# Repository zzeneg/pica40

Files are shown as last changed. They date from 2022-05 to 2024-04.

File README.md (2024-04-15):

# Pica40 v2

Split keyboard with 40 keys using XIAO controllers.

_Pica pica - european (common) magpie_

## Features

- 40 keys
- high profile (regular MX switches with hotswap sockets) or low profile (soldered low-profile ChocV2 switches)
- wired/wireless versions
- aggressive stagger
- slightly splayed for pinky columns

### Wired version

- XIAO RP2040 controller
- QMK firmware
- USB-C or TRRS connection between splits
- one rotary encoder (without click)
- status LED

### Wireless version

- XIAO nRF52840 BLE controller
- ZMK firmware
- two rotary encoders (without click, only master side encoder is currently supported by ZMK)
- on/off toggle
- battery connectors

> [!NOTE]
> I created a beta version with small improvements for wireless version - https://github.com/zzeneg/pica40/tree/v2.2-beta?tab=readme-ov-file#v22. I'm fairly confident it should work but I'm not able to verify it at the moment. You can order it at your own risk, let me know if everything worked.

## Photos

wired version with 3d printed case

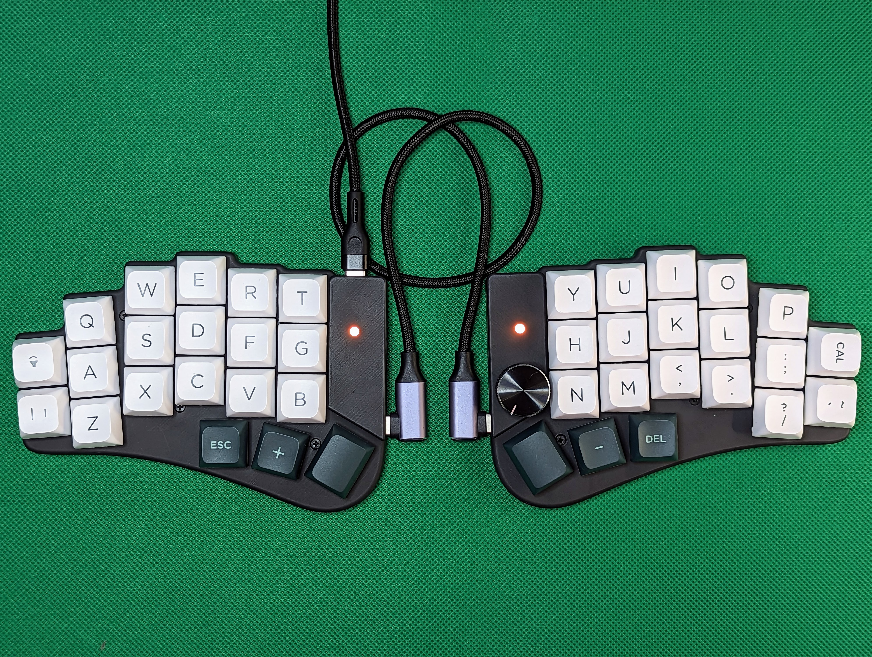
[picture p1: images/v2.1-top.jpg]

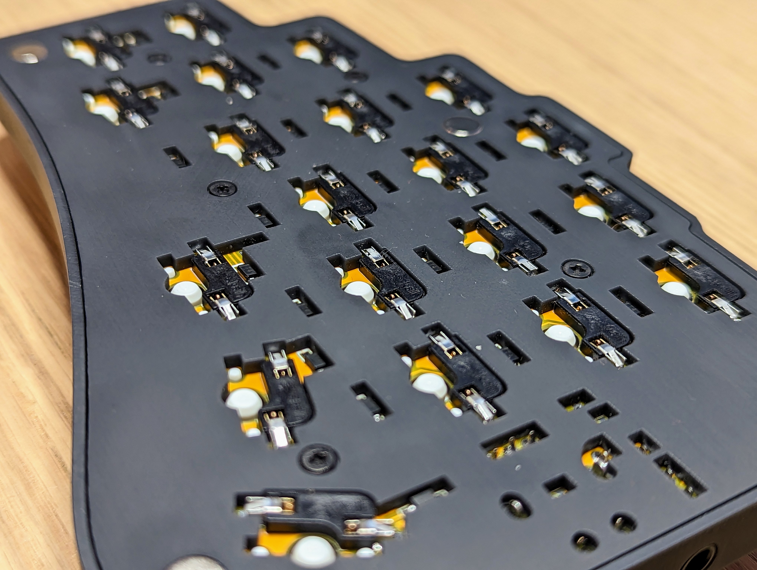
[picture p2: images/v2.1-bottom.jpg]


wired/wireless versions with Choc V2

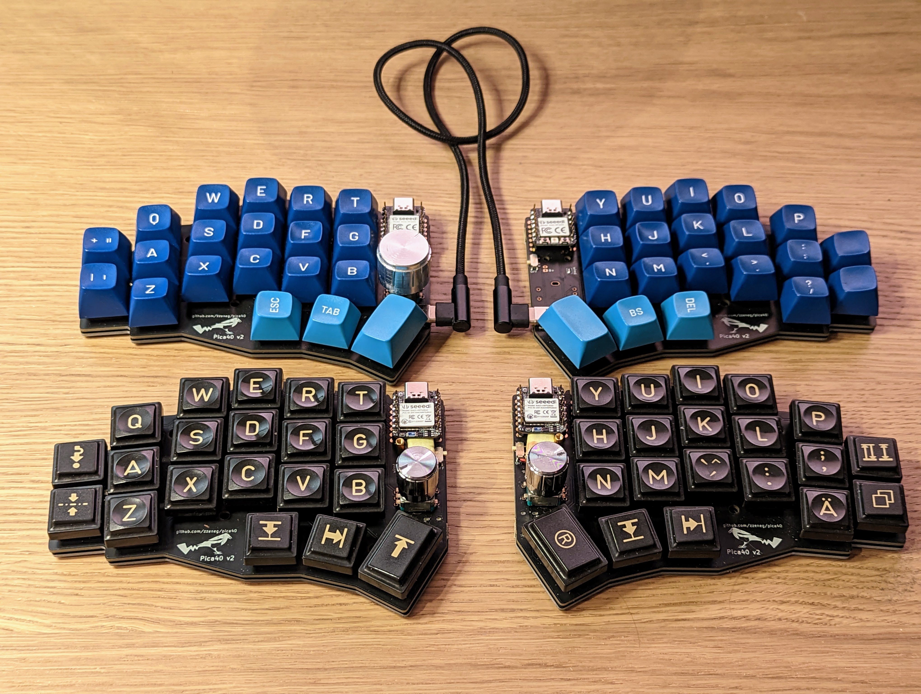
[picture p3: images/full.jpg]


Pica40 family - ChocV2 with low profile keycaps, ChocV2 with MT3 keycaps, Pica40 v1 with MT3 keycaps, regular switches and hotswap sockets

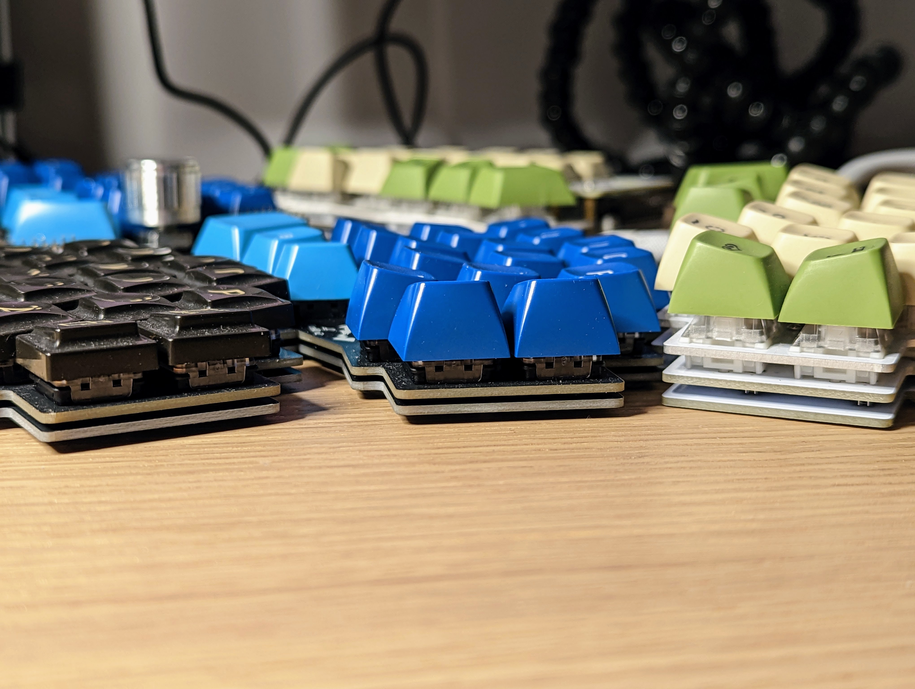
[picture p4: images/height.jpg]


## Firmware

- QMK - available in [main repository](https://github.com/qmk/qmk_firmware/tree/master/keyboards/pica40), also check [my fork](https://github.com/zzeneg/qmk_firmware/tree/feature/zzeneg/keyboards/pica40) for most recent updates. [Compiled file](firmware/qmk/pica40_rev2_zzeneg.uf2).
- Vial - [my fork](https://github.com/zzeneg/vial-qmk/tree/feature/zzeneg/keyboards/pica40). [Compiled file](firmware/vial/pica40_rev2_vial-zzeneg.uf2).
- ZMK - [Source code](https://github.com/zzeneg/zmk-config), [compiled left](firmware/zmk/pica40_left.uf2), [compiled right](firmware/zmk/pica40_right.uf2), [reset](firmware/zmk/settings_reset.uf2)

## Gerber files

- [PCB](./pcb/production/full.zip)
- [Bottom plate](./case/production/bottom.zip)

## Case files (STL - 3d printed, MX hotswap only)

All files are in [stl](./stl) folder.

### Top:

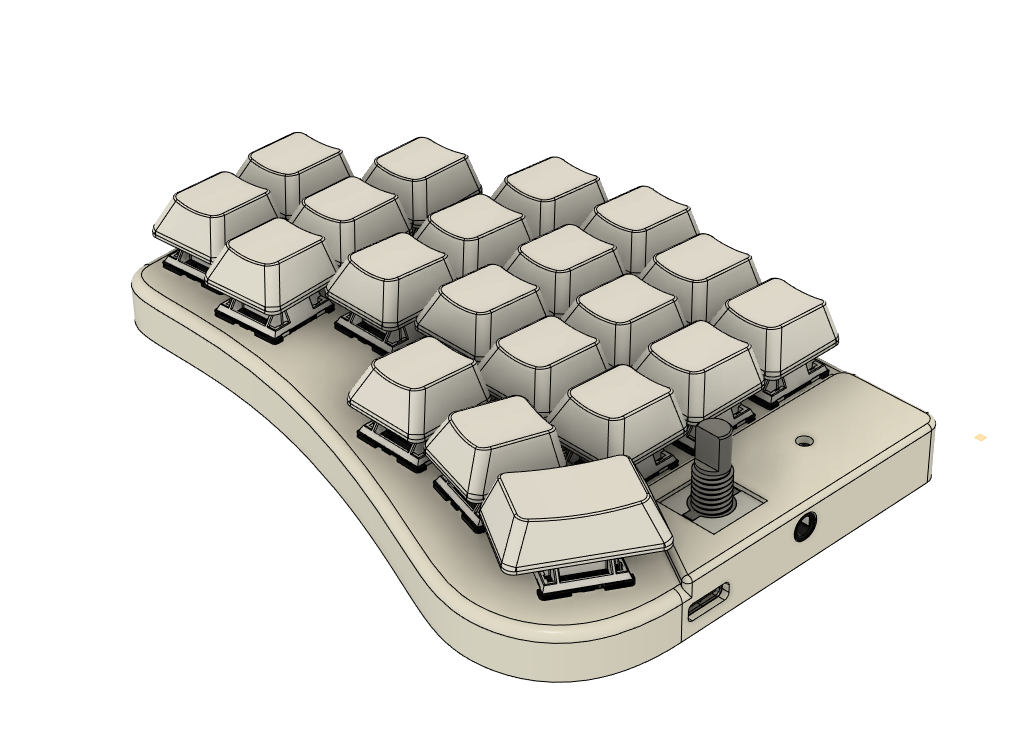
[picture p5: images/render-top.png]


- wired/wireless versions
- with and without encoders
- normal and thin versions (see bottom parts for difference)

### Bottom:

Normal version - solid cover, cutouts for legs.
Thin version - 1.2mm lower than normal version, cutouts for all elements. Has additional cutouts for magnets.

Thin vs normal:
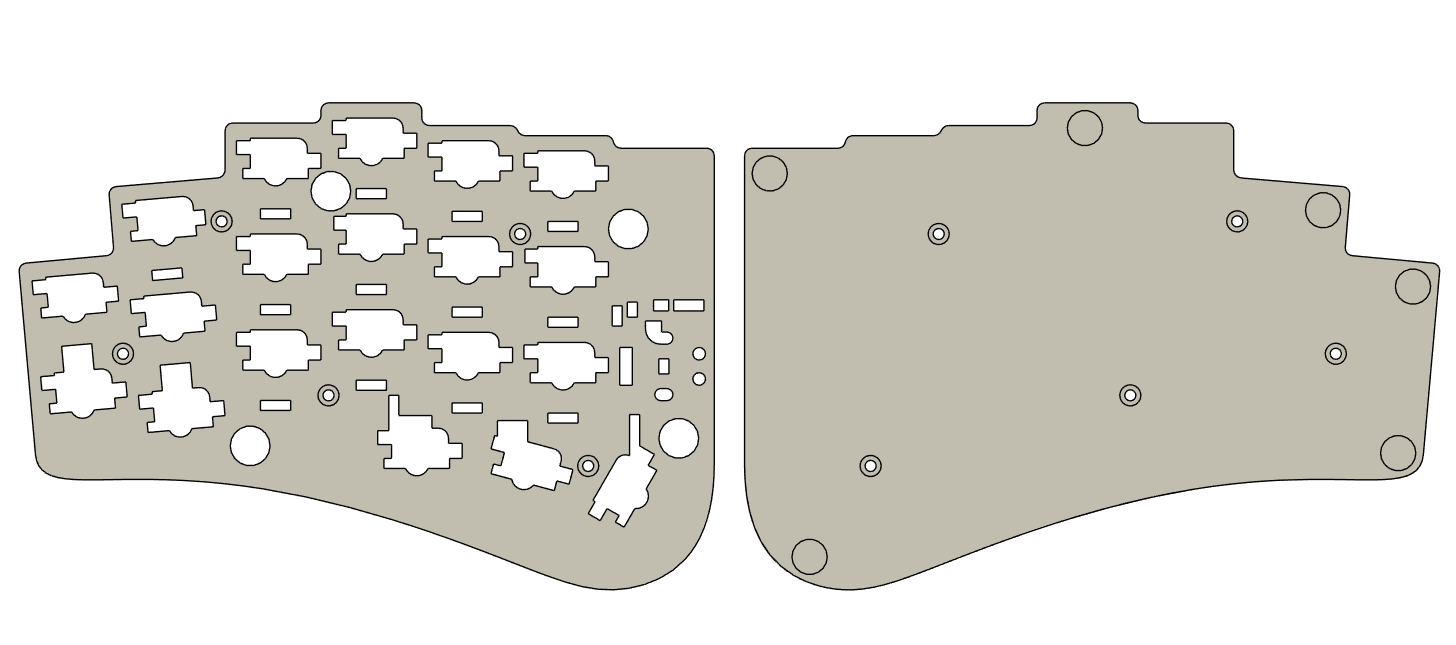
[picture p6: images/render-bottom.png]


## Case files (DXF - for metal/acrylic)

- [Curved bottom for MX hotswap with 3D printed case](dxf/bottom-curved.dxf)
- [Bottom for soldered ChocV2](dxf/bottom.dxf)
- [MCU cover](dxf/cover.dxf)
- [MCU cover with encoder hole](dxf/cover-hole.dxf)

## Bill of materials

- PCBs
- 2 XIAO MCUs - [RP2040](https://www.seeedstudio.com/XIAO-RP2040-v1-0-p-5026.html) for wired version, [nRF52840](https://www.seeedstudio.com/Seeed-XIAO-BLE-nRF52840-p-5201.html) for wireless
- 40 SMD SOD-123 1N4148 diodes
- 1 or 2 EC11/12 rotary encoder with knob (diameter up to 20mm)
- _[MX hotswap version]_ 3d printed case (top and bottom, left and right - 4 files)
- _[MX hotswap version]_ 40 hotswap sockets
- _[MX hotswap version]_ [M2 standoffs](https://www.aliexpress.com/item/4001271908929.html) (4mm for thin, 5mm for normal), 3mm [M2 screws with flat head](https://www.aliexpress.com/item/4001248931159.html)
- _[MX hotswap thin version]_ [8x2mm magnets](https://www.aliexpress.com/item/1005002285176336.html) (optional)
- _[ChocV2 soldered version]_ FR4/metal/acrylic bottom plates, metal/acrylic MCU cover (optional)
- _[ChocV2 soldered version]_ 6mm M2 screws, M2 nuts and washers
- _[Wired only]_ [USB-C 16pin connectors](https://www.aliexpress.com/item/1005003670899595.html)
- _[Wired only]_ [TRRS PJ-320A connectors](https://www.aliexpress.com/item/1005001928651798.html)
- _[Wireless only]_ [2x on/off toggle MSK-12C02](https://www.aliexpress.com/item/4000685483225.html)
- _[Wireless only]_ 2x Li-Ion 3.7V battery (up to 25x14x5 for standard case)
- [7mm legs](https://www.aliexpress.com/item/1005002995402961.html) or [rubber sheet](https://www.aliexpress.com/item/1005003938672544.html) (recommended for thin version)

## Build log

**TODO**

## Development

For proper KiCad setup install my [zzkeeb](https://github.com/zzeneg/zzkeeb/blob/main/README.md#installation) library.

## Changelog

### V2.1

- added TRRS support
- wired version supports rotary encoder on any side
- remove unused for FR4/acrylic/metal sandwich case, 3D printing is better and cheaper
- improved 3D printed case with a new shape and parts

### V2

- reworked to true split with two XIAO MCUs controllers
- added splay to pinky columns
- all case/pcb files are not compatible with V1

### V1

- split with single Pro Micro based MCU and handwired connection

## Support

If you like my work and want to support my future designs, please consider [sponsorship](https://github.com/sponsors/zzeneg).

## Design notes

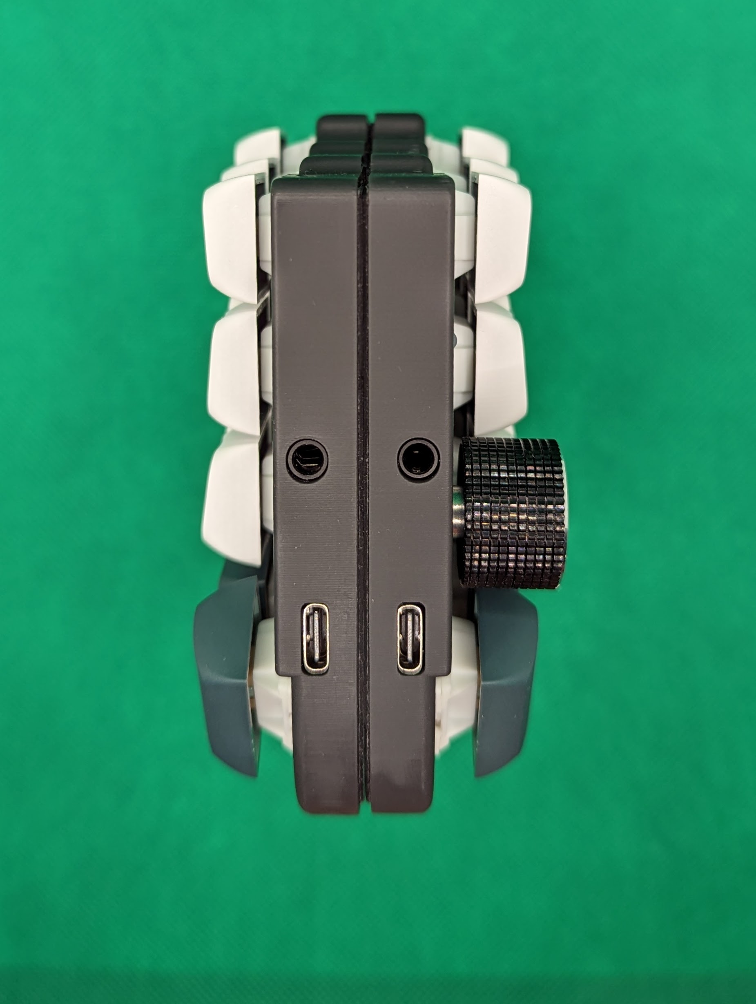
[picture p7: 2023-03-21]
images/v2.1-ports.jpg

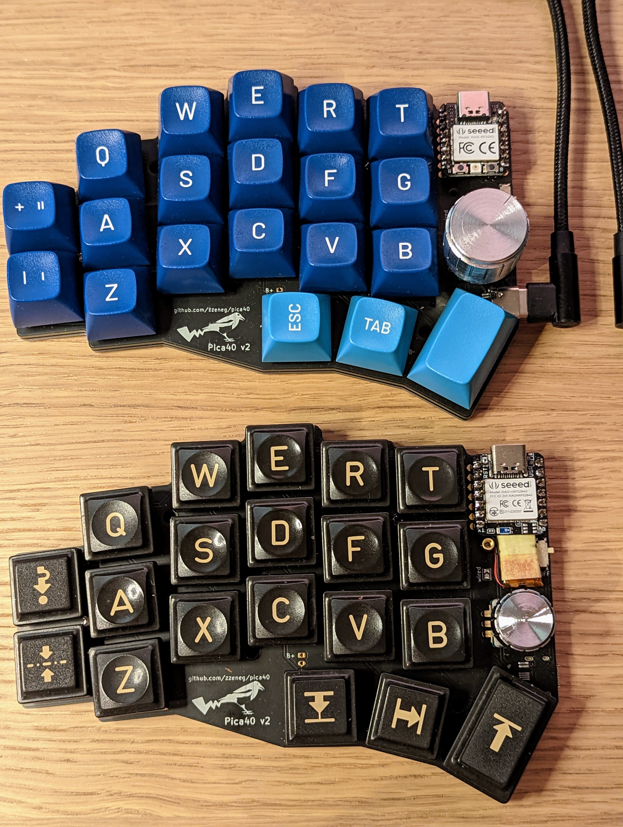
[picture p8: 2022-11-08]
images/left.jpg

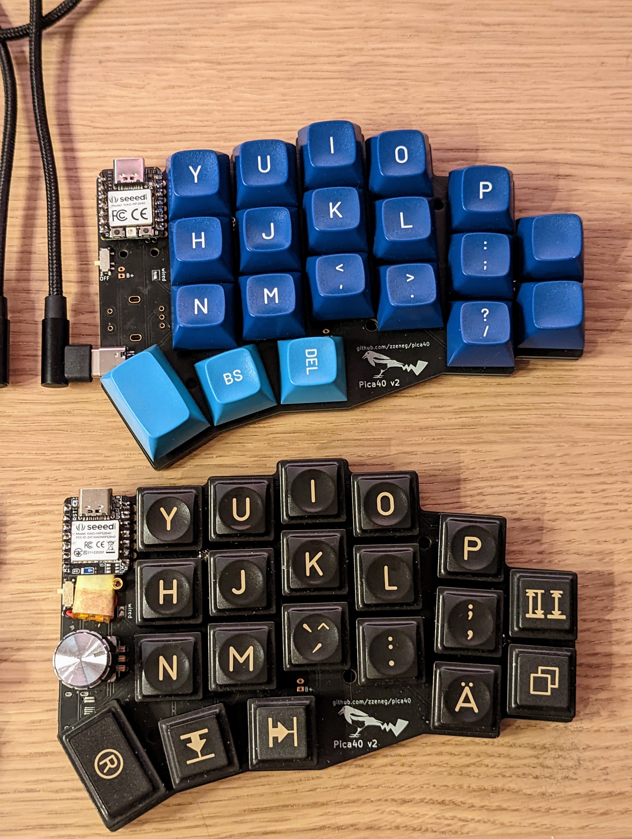
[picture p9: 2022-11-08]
images/right.jpg

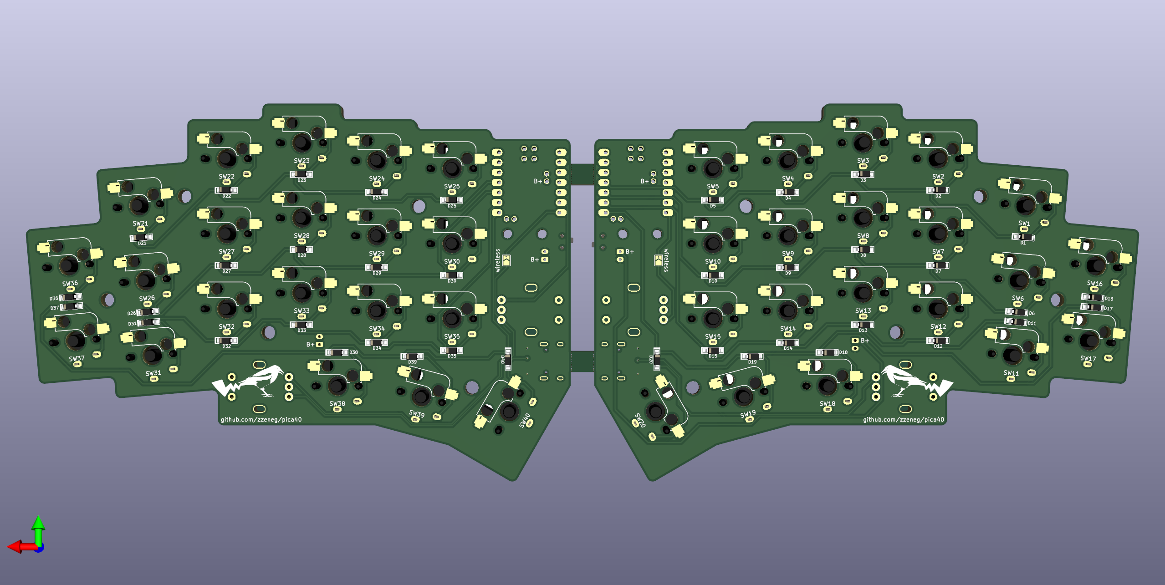
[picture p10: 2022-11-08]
pcba/bottom.png

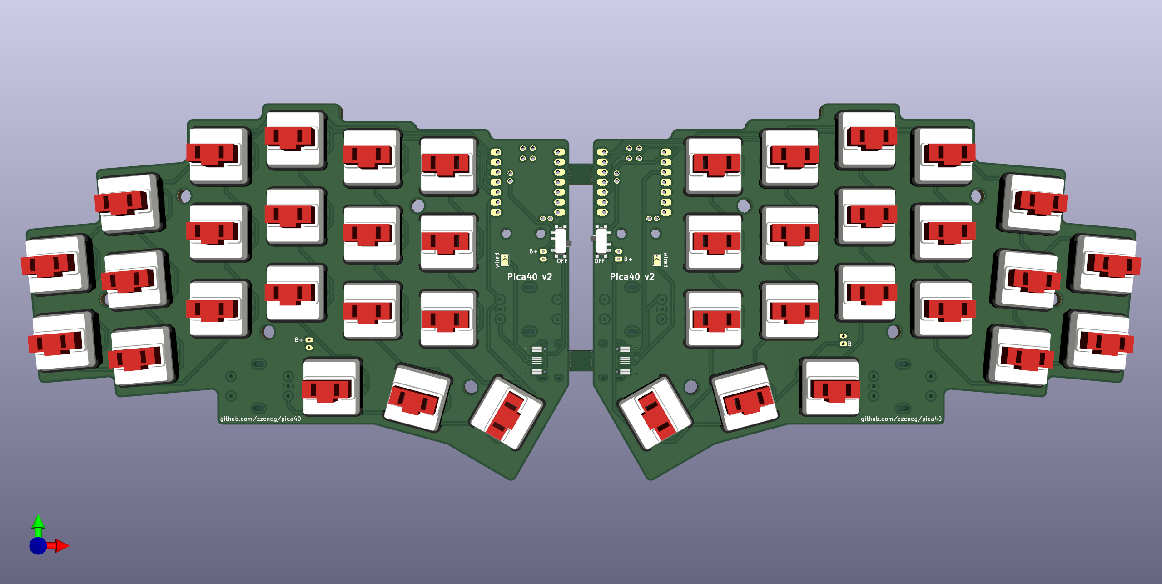
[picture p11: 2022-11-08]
pcba/top.png

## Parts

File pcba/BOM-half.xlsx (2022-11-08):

Designator | MPN/Seeed SKU | Qty | Link
D1,D2,D3,D4,D5,D6,D7,D8,D9,D10,D11,D12,D13,D14,D15,D16,D17,D18,D19,D20 | 1N4148W | 20 | https://file.elecfans.com/web1/M00/9B/4F/o4YBAF0kaAOAOa7_AAPvYDJhMOM395.pdf?filename=1N4148W.pdf
SW1,SW2,SW3,SW4,SW5,SW6,SW7,SW8,SW9,SW10,SW11,SW12,SW13,SW14,SW15,SW16,SW17,SW18,SW19,SW20 | CPG135301D02 | 20 | http://www.kailh.com/en/Products/Ks/CS/756.html
U1 | 102010469 | 1 | PLEASE DO NOT SOLDER https://www.seeedstudio.com/Seeed-XIAO-BLE-Sense-nRF52840-p-5253.html
BATTSW1 | K3-1296S-E2 | 1 | https://www.digikey.com/en/products/detail/c-k/PCM12SMTR/1640112

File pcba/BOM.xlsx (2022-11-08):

Designator | MPN/Seeed SKU | Qty | Link
D1,D2,D3,D4,D5,D6,D7,D8,D9,D10,D11,D12,D13,D14,D15,D16,D17,D18,D19,D20,D21,D22,D23,D24,D25,D26,D27,D28,D29,D30,D31,D32,D33,D34,D35,D36,D37,D38,D39,D40 | 1N4148W | 40 | https://file.elecfans.com/web1/M00/9B/4F/o4YBAF0kaAOAOa7_AAPvYDJhMOM395.pdf?filename=1N4148W.pdf
SW1,SW2,SW3,SW4,SW5,SW6,SW7,SW8,SW9,SW10,SW11,SW12,SW13,SW14,SW15,SW16,SW17,SW18,SW19,SW20,SW21,SW22,SW23,SW24,SW25,SW26,SW27,SW28,SW29,SW30,SW31,SW32,SW33,SW34,SW35,SW36,SW37,SW38,SW39,SW40 | CPG135301D02 | 40 | http://www.kailh.com/en/Products/Ks/CS/756.html
U1,U2 | 102010469 | 2 | PLEASE DO NOT SOLDER https://www.seeedstudio.com/Seeed-XIAO-BLE-Sense-nRF52840-p-5253.html
BATTSW1,BATTSW2 | K3-1296S-E2 | 2 | https://www.digikey.com/en/products/detail/c-k/PCM12SMTR/1640112

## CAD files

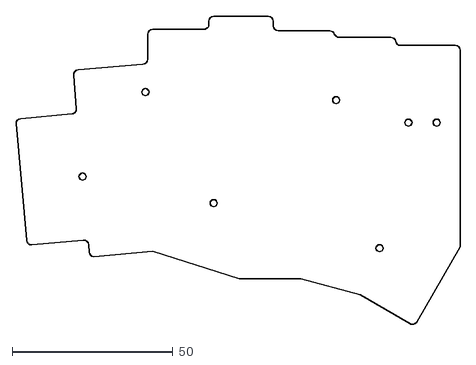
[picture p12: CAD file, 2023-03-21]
dxf/bottom.dxf
137.9 x 95.8

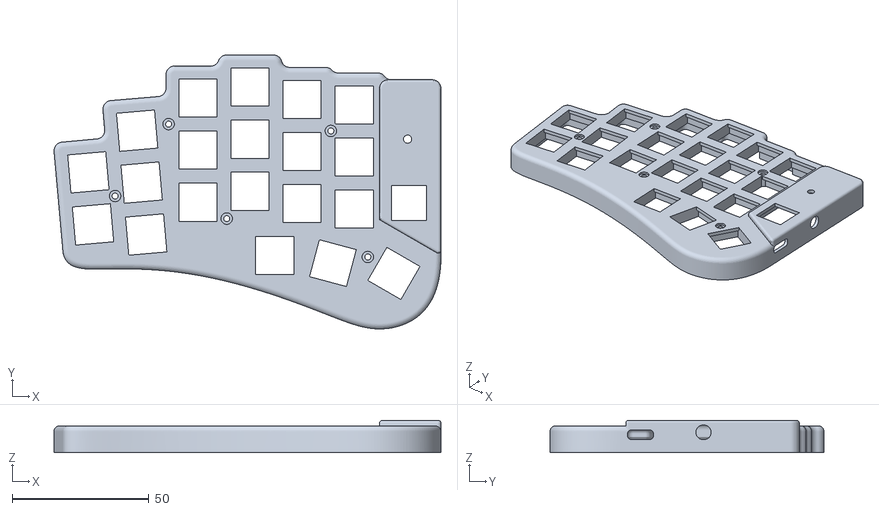
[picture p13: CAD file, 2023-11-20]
stl/top_case v26_left-wired.stl
141.2 x 100.0 x 11.8

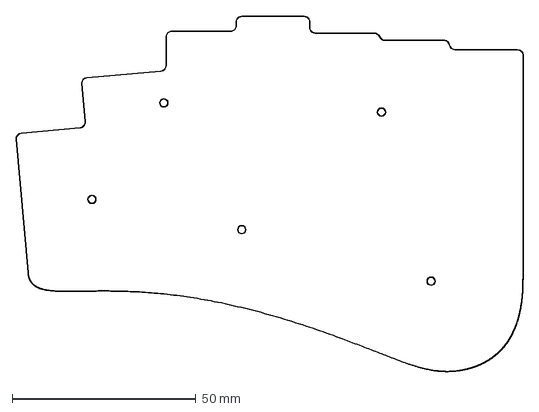
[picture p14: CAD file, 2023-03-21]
dxf/bottom-curved.dxf
137.9 x 96.6 mm

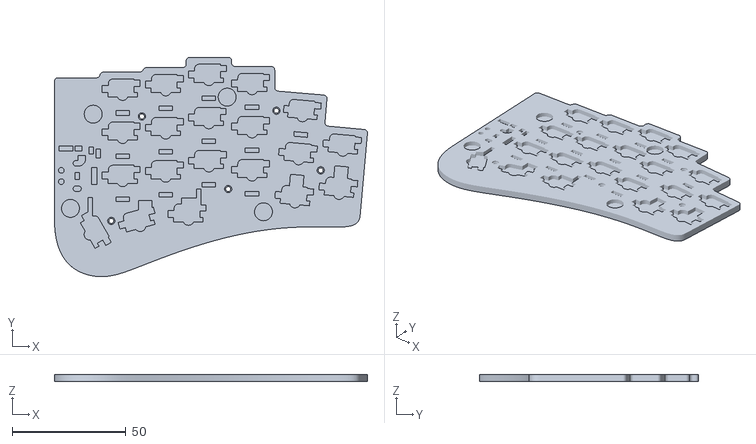
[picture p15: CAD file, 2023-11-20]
stl/bottom_case v26_right.stl
137.8 x 96.6 x 3.20

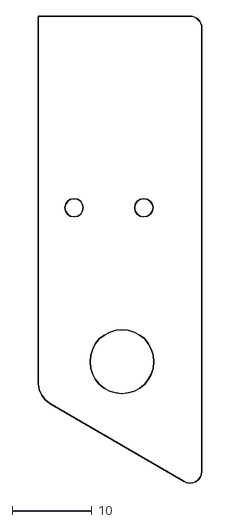
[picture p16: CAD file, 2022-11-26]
dxf/cover-hole.dxf
20.5 x 58.6

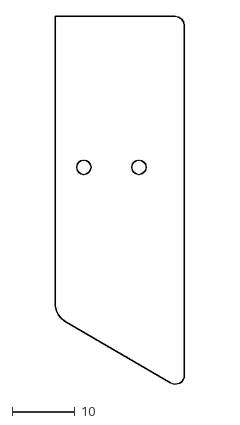
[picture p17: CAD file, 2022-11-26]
dxf/cover.dxf
20.5 x 58.6

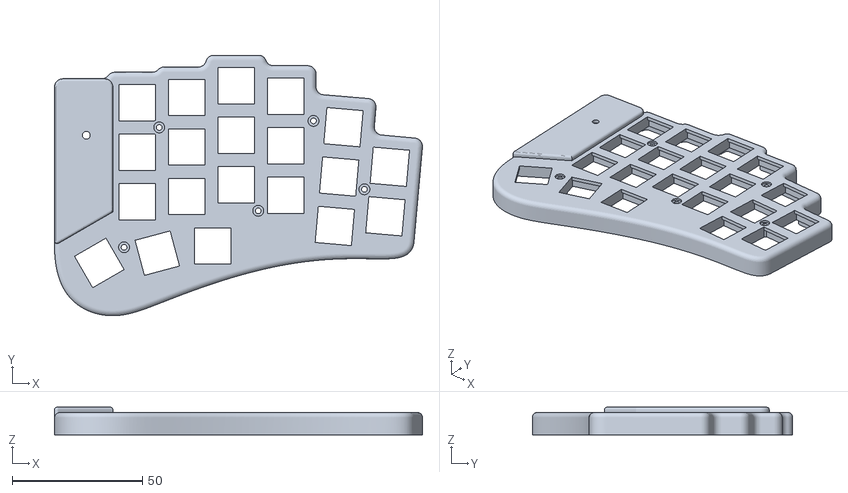
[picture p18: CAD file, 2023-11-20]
stl/top_case v26_right-wired-no-enc-thin.stl
141.2 x 100.0 x 10.6

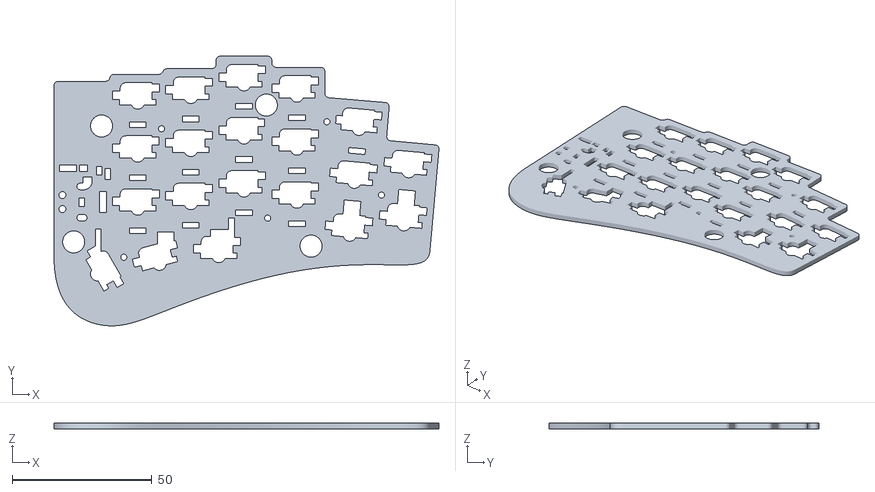
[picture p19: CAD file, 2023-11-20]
stl/bottom_case v26_right-thin.stl
137.8 x 96.6 x 2.00

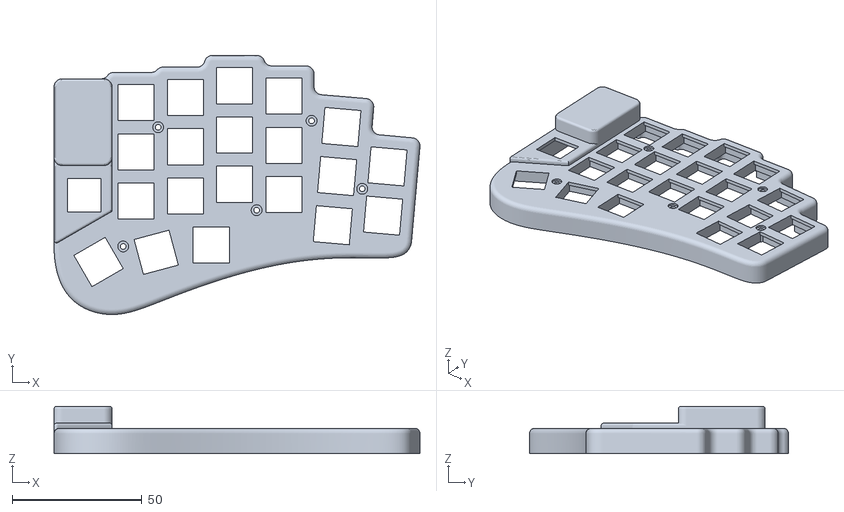
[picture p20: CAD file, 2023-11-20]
stl/top_case v26_right-wireless-battery.stl
141.2 x 100.0 x 18.3

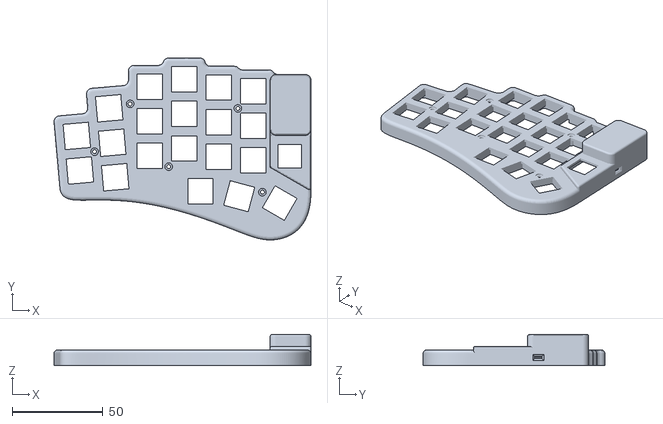
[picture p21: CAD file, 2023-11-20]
stl/top_case v26_left-wireless-battery-thin.stl
141.2 x 100.0 x 17.1

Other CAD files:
stl/top_case v26_right-wired-no-enc.stl
stl/top_case v26_left-wired-thin.stl
stl/top_case v26_right-wireless.stl
stl/top_case v26_right-wired-thin.stl
stl/top_case v26_left-wireless-thin.stl
stl/top_case v26_left-wireless-battery.stl
stl/top_case v26_right-wireless-thin.stl
stl/top_case v26_left-wired-no-enc-thin.stl
case/pcb.f3d
stl/bottom_case v26_left-thin.stl
stl/bottom_case v26_left.stl
stl/top_case v26_left-wired-no-enc.stl
stl/top_case v26_left-wireless.stl
stl/top_case v26_right-wired.stl
stl/top_case v26_right-wireless-battery-thin.stl

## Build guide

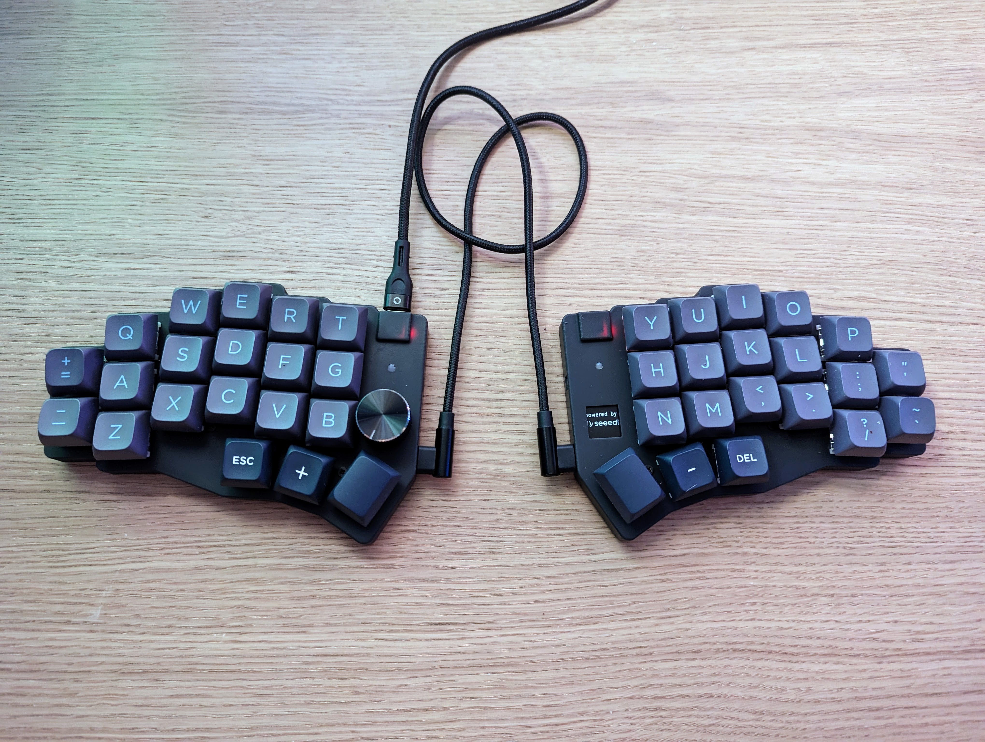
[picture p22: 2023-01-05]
images/3d-printed-case.jpg

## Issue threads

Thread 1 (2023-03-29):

Encoder(s) setup clarification

2ynn, 2023-03-29:
Great design! thanks for sharing.

If I understand correctly, for the wired configuration (XIAO RP2040, left as master) I can only get a single encoder.

According to your [QMK info.json](https://github.com/qmk/qmk_firmware/blob/f56580404d44af8a0e8b7205618c084a9acb3772/keyboards/pica40/rev2/info.json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), both ENC_A and ENC_B pads are connected to GP27.

I assume then that I should close jumpers JP6 (passing data to left side), JP3 (receiving data from right side) and JP1 (joining both encoder pins). Is that correct?

In this configuration, I am confused as to how you are able to detect the direction of the rotation. Is there a QMK configuration I am missing?

Thanks!

zzeneg, 2023-03-30:
Hi! Thanks for the interest!
Encoder logic is a bit tricky and unique, as there is only 1 free pin on every MCU.
You are correct that you need to close those jumpers, and by doing so you are connecting encoder's B pin to the MCU on another half (using 4th wire in TRRS/USB-C connection).
There is [custom code](https://github.com/qmk/qmk_firmware/blob/f56580404d44af8a0e8b7205618c084a9acb3772/keyboards/pica40/rev2/rev2.c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) for encoder logic which looks intimidating but it only changes reading second pin's state from split transport transaction instead of a physical pin.
ENC_B from configuration is not used and added only because QMK validates it.

2ynn, 2023-03-30:
Thanks for your response, this is brilliant!

I think I got the jumpers wrong then. If i want the encoder on the left side (master),  I should leave JP1 open (to not short the encoder) but close JP4 to connect `ENCB ==ttrs== ENCB_r` to `ENCA_r` , which is then read by the `encoders_pad_b_[0] = GP27` on the right side (slave) and then processed by `encoder_sync_slave_handler()`

So if I understand well setting `ENCODERS_PAD_B` to [GP27] actually matters in your custom code, not just for QMK, since you are always reading ENC_A/ENC_A_r (in the Wired configuration at least).

zzeneg, 2023-03-30:
You should bridge the "no enc" jumper on a half without encoder, if it makes more sense :)
Actually I use A/B in code interchangeably, since it will always be the same single pin on any side. I simplified it a bit in my dev branch - https://github.com/zzeneg/qmk_firmware/blob/feature/pica40/keyboards/pica40/rev2/rev2.c, just didn't open PR to main repo yet.

Closed 2023-03-30.

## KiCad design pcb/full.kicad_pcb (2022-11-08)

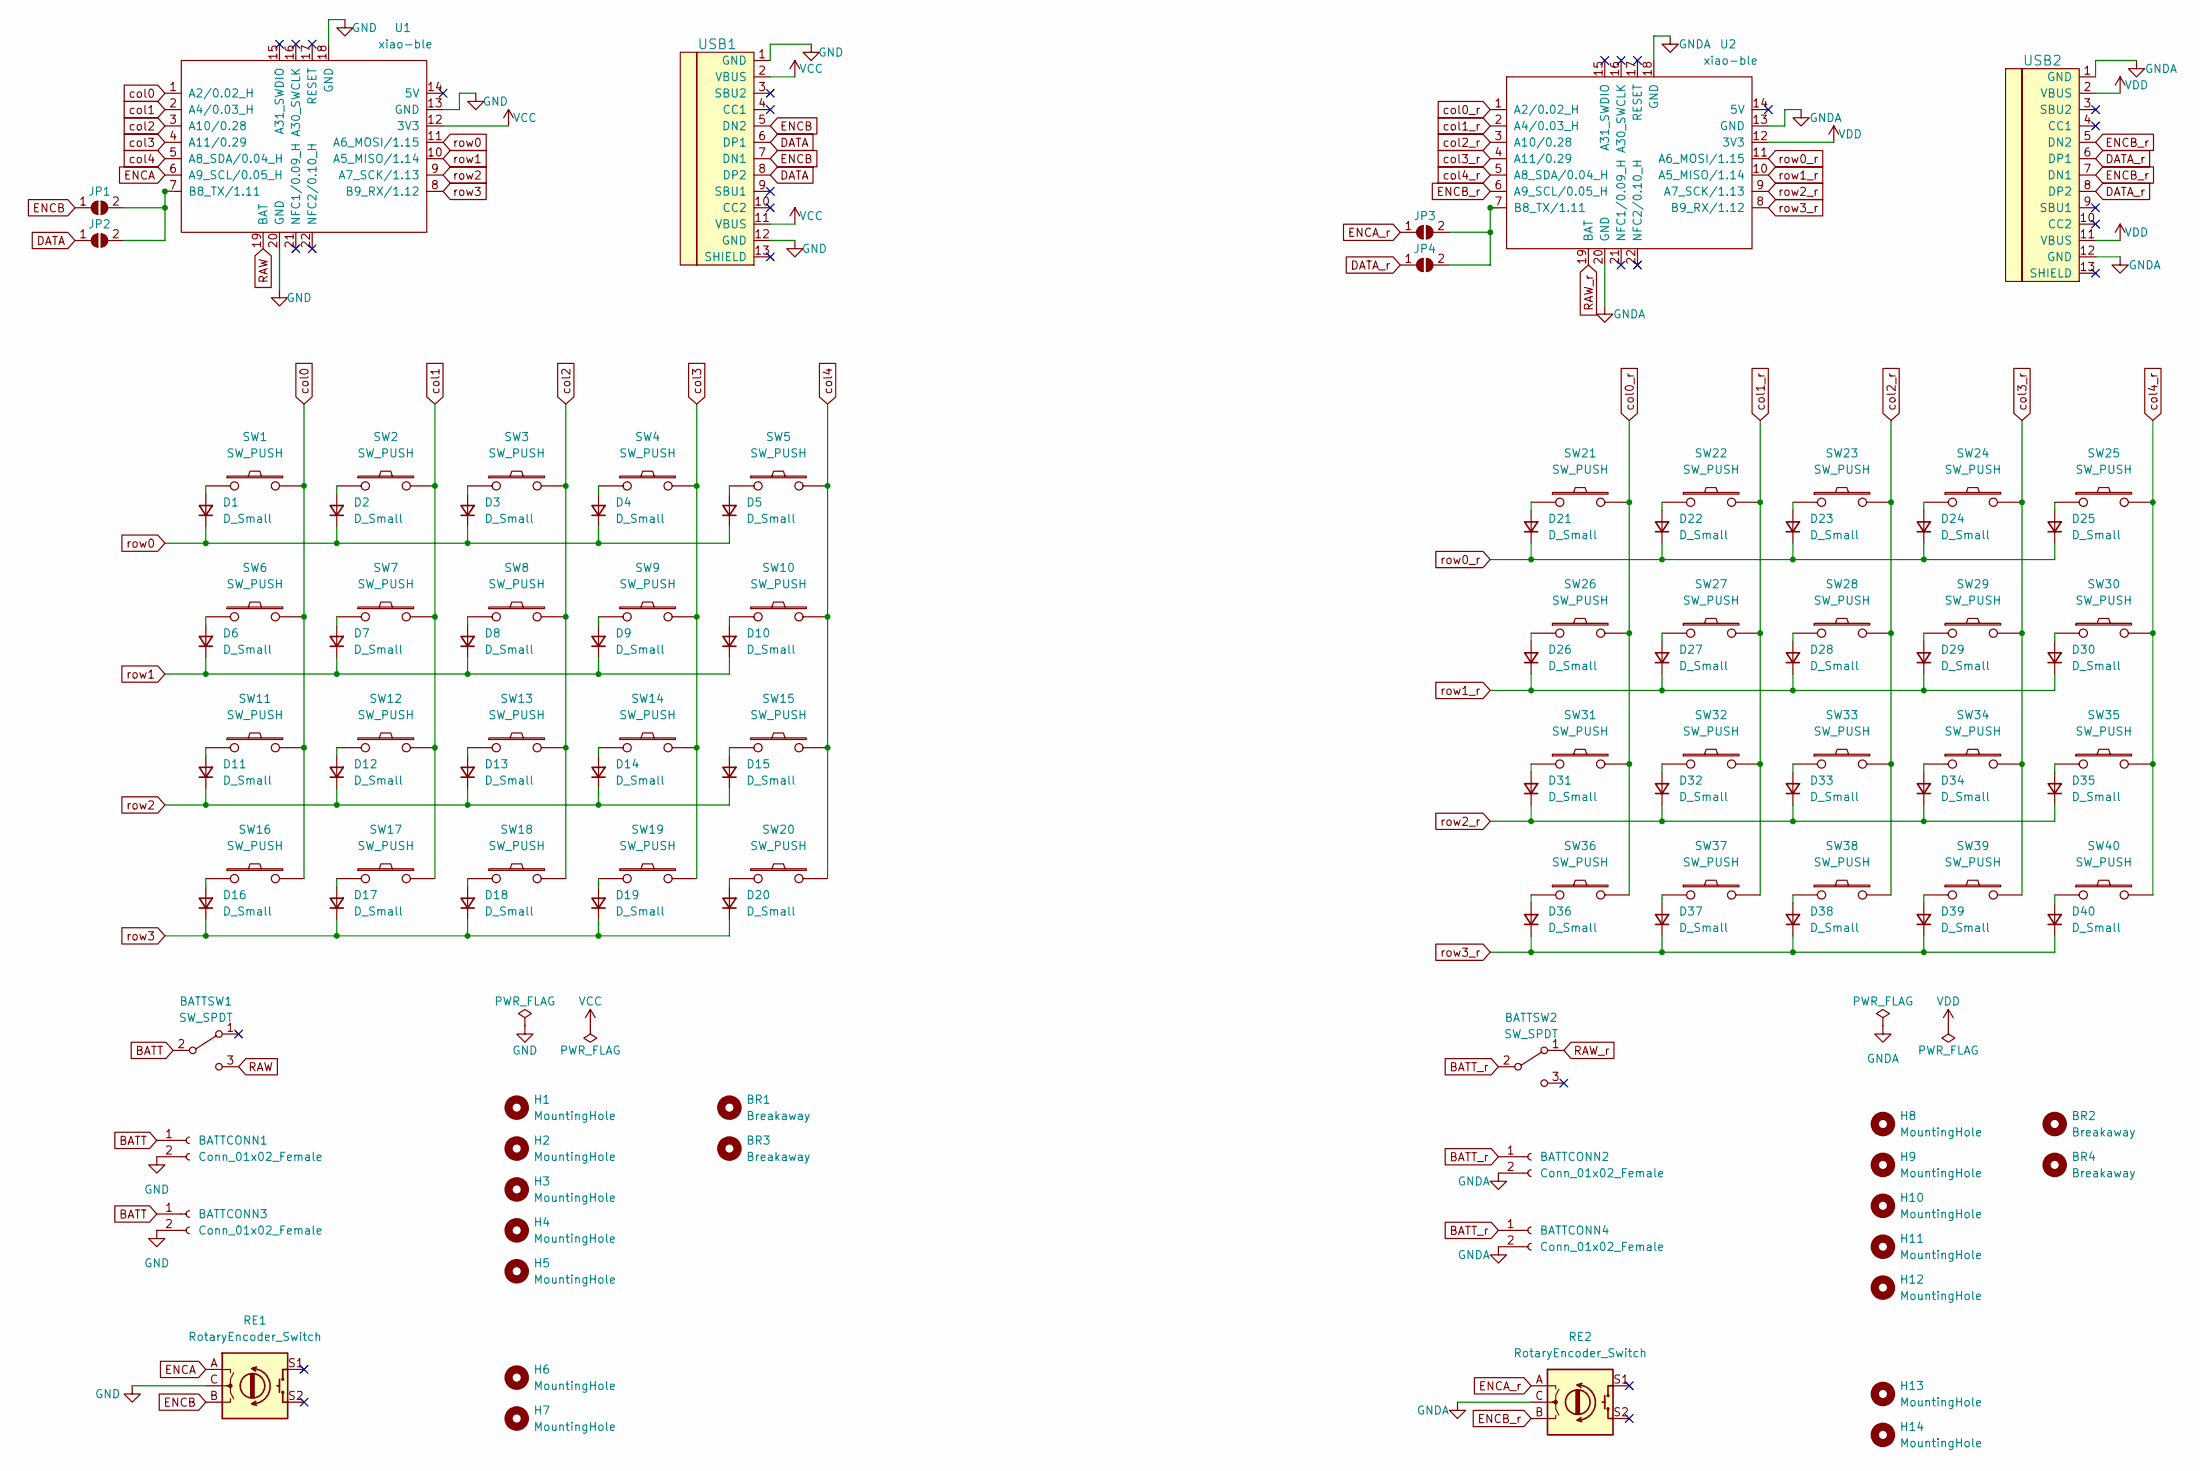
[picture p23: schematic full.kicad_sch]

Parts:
BATTCONN1, BATTCONN2, BATTCONN3, BATTCONN4: Conn_01x02_Female; JST_PH_S2B-PH-K_1x02_P2.00mm
BATTSW1, BATTSW2: SW_SPDT; SW_SPDT_PCM12
BR1, BR2, BR3, BR4: Breakaway; Breakaway_Tabs
D1, D2, D3, D4, D5, D6, D7, D8, D9, D10, D11, D12, D13, D14, D15, D16, D17, D18, D19, D20, D21, D22, D23, D24, D25, D26, D27, D28, D29, D30, D31, D32, D33, D34, D35, D36, D37, D38, D39, D40: D_Small; D3_SMD
H1, H2, H3, H4, H5, H8, H9, H10, H11, H12: MountingHole; spacer_m2_3.4
H6, H7, H13, H14: MountingHole; thread_m2
JP1, JP2, JP3, JP4: SolderJumper_2_Open; SolderJumper-2_P1.3mm_Open_TrianglePad1.0x1.5mm
RE1, RE2: RotaryEncoder_Switch; RotaryEncoder_EC11
SW1, SW2, SW3, SW4, SW5, SW6, SW7, SW8, SW9, SW10, SW11, SW12, SW13, SW14, SW15, SW16, SW17, SW18, SW19, SW21, SW22, SW23, SW24, SW25, SW26, SW27, SW28, SW29, SW30, SW31, SW32, SW33, SW34, SW35, SW36, SW37, SW38, SW39: SW_PUSH; CherryMX_Hotswap_ChocV2
SW20, SW40: SW_PUSH; CherryMX_Hotswap_ChocV2_1.5
U1, U2: xiao-ble; xiao-ble-tht
USB1, USB2: HRO-TYPE-C-31-M-12; HRO-TYPE-C-31-M-12-data

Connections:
BATT: BATTCONN1.1, BATTCONN3.1, BATTSW1.2 (B)
BATT_r: BATTCONN2.1, BATTCONN4.1, BATTSW2.2 (B)
DATA: JP2.1 (A), USB1.6 (DP1), USB1.8 (DP2)
DATA_r: JP4.1 (A), USB2.6 (DP1), USB2.8 (DP2)
ENCA: RE1.A, U1.6 (A9_SCL/0.05_H)
ENCA_r: JP3.1 (A), RE2.A
ENCB: JP1.1 (A), RE1.B, USB1.5 (DN2), USB1.7 (DN1)
ENCB_r: RE2.B, U2.6 (A9_SCL/0.05_H), USB2.5 (DN2), USB2.7 (DN1)
GND: BATTCONN1.2, BATTCONN3.2, RE1.C, U1.13 (GND), U1.18 (GND), U1.20 (GND), USB1.1 (GND), USB1.12 (GND)
GNDA: BATTCONN2.2, BATTCONN4.2, RE2.C, U2.13 (GND), U2.18 (GND), U2.20 (GND), USB2.1 (GND), USB2.12 (GND)
unnamed: D1.2 (A), SW1.1
unnamed: D2.2 (A), SW2.1
unnamed: D3.2 (A), SW3.1
unnamed: D4.2 (A), SW4.1
unnamed: D5.2 (A), SW5.1
unnamed: D6.2 (A), SW6.1
unnamed: D7.2 (A), SW7.1
unnamed: D8.2 (A), SW8.1
unnamed: D9.2 (A), SW9.1
unnamed: D10.2 (A), SW10.1
unnamed: D11.2 (A), SW11.1
unnamed: D12.2 (A), SW12.1
unnamed: D13.2 (A), SW13.1
unnamed: D14.2 (A), SW14.1
unnamed: D15.2 (A), SW15.1
unnamed: D16.2 (A), SW16.1
unnamed: D17.2 (A), SW17.1
unnamed: D18.2 (A), SW18.1
unnamed: D19.2 (A), SW19.1
unnamed: D20.2 (A), SW20.1
unnamed: D21.2 (A), SW21.1
unnamed: D22.2 (A), SW22.1
unnamed: D23.2 (A), SW23.1
unnamed: D24.2 (A), SW24.1
unnamed: D25.2 (A), SW25.1
unnamed: D26.2 (A), SW26.1
unnamed: D27.2 (A), SW27.1
unnamed: D28.2 (A), SW28.1
unnamed: D29.2 (A), SW29.1
unnamed: D30.2 (A), SW30.1
unnamed: D31.2 (A), SW31.1
unnamed: D32.2 (A), SW32.1
unnamed: D33.2 (A), SW33.1
unnamed: D34.2 (A), SW34.1
unnamed: D35.2 (A), SW35.1
unnamed: D36.2 (A), SW36.1
unnamed: D37.2 (A), SW37.1
unnamed: D38.2 (A), SW38.1
unnamed: D39.2 (A), SW39.1
unnamed: D40.2 (A), SW40.1
unnamed: JP1.2 (B), JP2.2 (B), U1.7 (B8_TX/1.11)
unnamed: JP3.2 (B), JP4.2 (B), U2.7 (B8_TX/1.11)
RAW: BATTSW1.3 (C), U1.19 (BAT)
RAW_r: BATTSW2.1 (A), U2.19 (BAT)
VCC: U1.12 (3V3), USB1.2 (VBUS), USB1.11 (VBUS)
VDD: U2.12 (3V3), USB2.2 (VBUS), USB2.11 (VBUS)
col0: SW1.2, SW6.2, SW11.2, SW16.2, U1.1 (A2/0.02_H)
col0_r: SW21.2, SW26.2, SW31.2, SW36.2, U2.1 (A2/0.02_H)
col1: SW2.2, SW7.2, SW12.2, SW17.2, U1.2 (A4/0.03_H)
col1_r: SW22.2, SW27.2, SW32.2, SW37.2, U2.2 (A4/0.03_H)
col2: SW3.2, SW8.2, SW13.2, SW18.2, U1.3 (A10/0.28)
col2_r: SW23.2, SW28.2, SW33.2, SW38.2, U2.3 (A10/0.28)
col3: SW4.2, SW9.2, SW14.2, SW19.2, U1.4 (A11/0.29)
col3_r: SW24.2, SW29.2, SW34.2, SW39.2, U2.4 (A11/0.29)
col4: SW5.2, SW10.2, SW15.2, SW20.2, U1.5 (A8_SDA/0.04_H)
col4_r: SW25.2, SW30.2, SW35.2, SW40.2, U2.5 (A8_SDA/0.04_H)
row0: D1.1 (K), D2.1 (K), D3.1 (K), D4.1 (K), D5.1 (K), U1.11 (A6_MOSI/1.15)
row0_r: D21.1 (K), D22.1 (K), D23.1 (K), D24.1 (K), D25.1 (K), U2.11 (A6_MOSI/1.15)
row1: D6.1 (K), D7.1 (K), D8.1 (K), D9.1 (K), D10.1 (K), U1.10 (A5_MISO/1.14)
row1_r: D26.1 (K), D27.1 (K), D28.1 (K), D29.1 (K), D30.1 (K), U2.10 (A5_MISO/1.14)
row2: D11.1 (K), D12.1 (K), D13.1 (K), D14.1 (K), D15.1 (K), U1.9 (A7_SCK/1.13)
row2_r: D31.1 (K), D32.1 (K), D33.1 (K), D34.1 (K), D35.1 (K), U2.9 (A7_SCK/1.13)
row3: D16.1 (K), D17.1 (K), D18.1 (K), D19.1 (K), D20.1 (K), U1.8 (B9_RX/1.12)
row3_r: D36.1 (K), D37.1 (K), D38.1 (K), D39.1 (K), D40.1 (K), U2.8 (B9_RX/1.12)

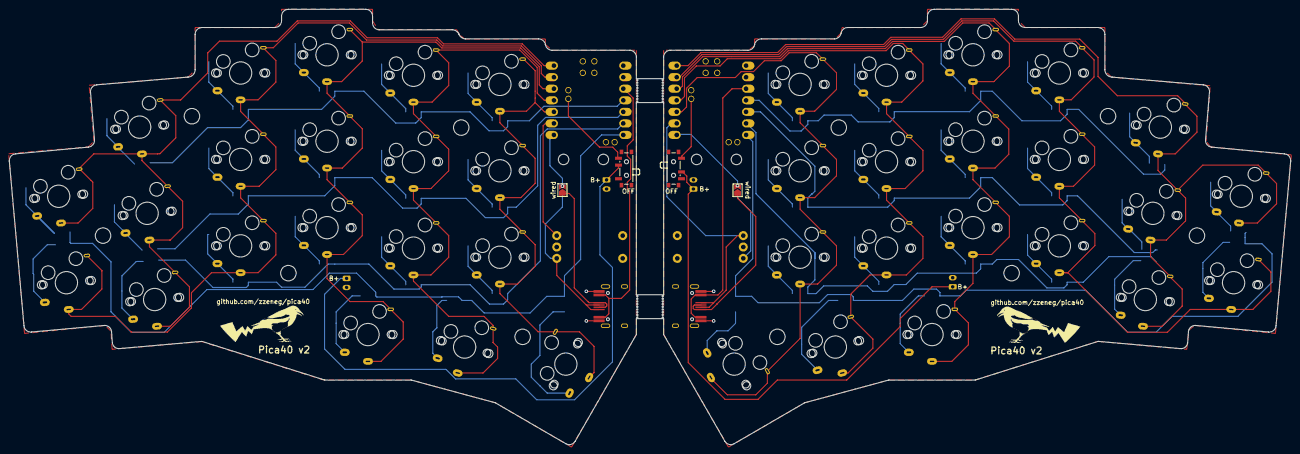
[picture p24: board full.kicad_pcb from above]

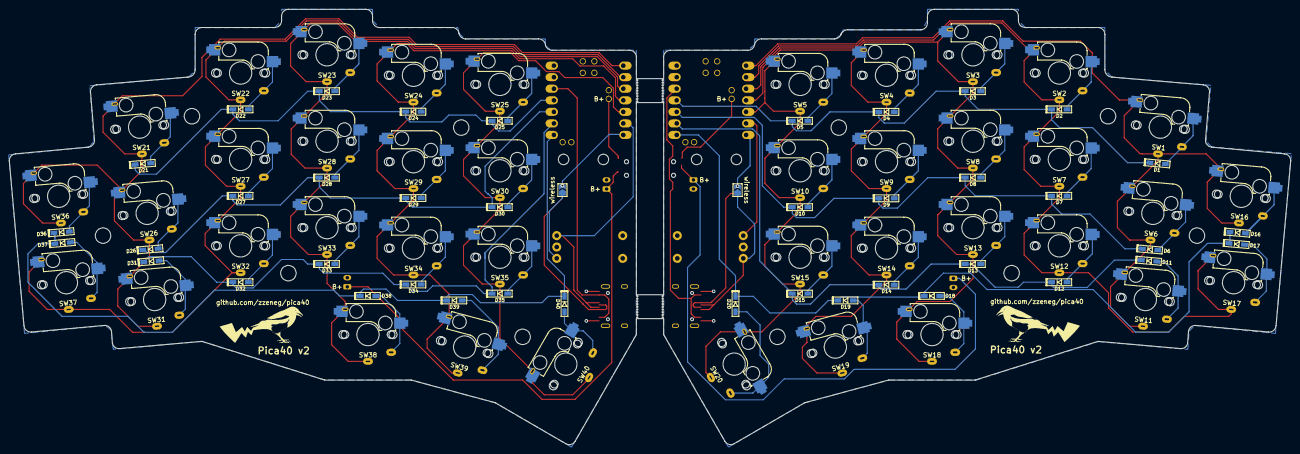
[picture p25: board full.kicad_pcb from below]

Board: 2 copper layers, 281.7 x 95.7 mm, 114 parts (49 on the bottom side), 74 nets.

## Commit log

2022-05-12 add pcb
    [pica40.kicad_pcb, pica40.kicad_sch]
2022-05-12 update gerber
2022-05-13 fix 3d model
    [pica40.kicad_pcb]
2022-05-14 flip oled jumpers
    [pica40.kicad_pcb]
2022-05-18 logos and jlcpcb texts
    [pica40.kicad_pcb]
2022-05-24 add breakaway plate, replace battery connector
    [pica40.kicad_pcb, pica40.kicad_sch]
2022-05-24 move diodes
    [pica40.kicad_pcb]
2022-05-25 generate dxf files
    [bottom.dxf, cover.dxf, pica40.kicad_pcb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]
2022-05-25 fix gerbers
2022-05-25 add bottom-tenting, reorganize
    [bottom-metal-tenting.kicad_pcb, bottom-metal.kicad_pcb, bottom-tenting.dxf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]
2022-06-08 update breakaway design to satisfy jlcpcb
    [bottom.kicad_pcb, top-cover.kicad_pcb]
2022-06-09 update and reroute
    [pica40.kicad_pcb, pica40.kicad_sch]
2022-06-10 update case files
    [bottom-metal-tenting.kicad_pcb, bottom-metal.kicad_pcb, bottom-tenting.dxf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]
2022-06-12 remove logos from top
    [cover.kicad_pcb, top.kicad_pcb]
2022-06-12 use footprints with PTH slots
    [pica40.kicad_pcb]
2022-06-13 separate plates
    [top-left.kicad_pcb, top-metal-right.kicad_pcb, top-right.kicad_pcb]
2022-06-13 Revert "use footprints with PTH slots"
    This reverts commit bdcc6b4fc5c42f5b6ab726123ea9fec0ebe93fb2.
    [pica40.kicad_pcb]
2022-06-13 fix LED footprint
    [pica40.kicad_pcb]
2022-07-16 non-reversible pcbs
    [bottom-metal-tenting.kicad_pcb, bottom-metal.kicad_pcb, bottom-tenting.dxf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]
2022-07-16 update 3d models and renders
    [left.kicad_pcb]
2022-08-08 improve rotary encoder footprint
    [right.kicad_pcb]
2022-08-11 add full version
    [full.kicad_pcb, full.kicad_sch, left.kicad_pcb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]
2022-08-13 rounded traces
2022-09-14 remove second encoder
    [full.kicad_sch, left.kicad_pcb, left.kicad_sch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]
2022-09-22 update cover
    [cover.dxf, cover.kicad_pcb]
2022-09-22 update bottom-tenting
    [bottom-metal-tenting.kicad_pcb, bottom-tenting.dxf]
2022-11-08 add big cover
    [cover-big.dxf, cover-big.kicad_pcb]
2022-11-08 cover without hole
    [cover-big-hole.dxf, cover-big-hole.kicad_pcb]
2022-11-10 adjust top plate, add new cover in PCB style
    [cover-big-hole-acrylic.kicad_pcb, cover-big-hole.kicad_pcb, top-metal.kicad_pcb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]
2022-11-11 fix DXF files for new covers
    [cover-big-hole-acrylic.kicad_pcb, cover-big-hole.dxf, cover-big.dxf]
2022-11-15 remove small cover
    [cover-big.dxf, cover-big.kicad_pcb, cover-hole-acrylic.kicad_pcb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]
2022-11-16 udpate pcb, remove unused files
    [BOM-half.xlsx, BOM.xlsx, full.kicad_sch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]
2022-11-26 improve footprints and routing
    [left.kicad_pcb, right.kicad_pcb]
2022-11-26 fix dxf files
    [bottom-metal-tenting.kicad_pcb, bottom-metal.kicad_pcb, bottom-tenting.dxf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]
2022-12-15 add top left/right/full case files
    [top-full.kicad_pcb, top-left.kicad_pcb, top-right.kicad_pcb]
2022-12-20 add STLs
    [Plate.f3d, Top-left-enc.stl, Top-right-enc.stl]
2022-12-21 add bottom cutout
    [Bottom-cutout.stl, BottomCutout.f3d, bottom-cutout-Edge_Cuts.dxf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]
2022-12-21 add bottom cutout for chocs
    [Bottom-cutout-choc.stl, bottom-cutout-choc-Edge_Cuts.dxf, bottom-cutout-choc.kicad_pcb]
2022-12-23 remove zones from bottom to prevent shorting
    [bottom.kicad_pcb]
2023-01-05 update case files, remove left/right files, update readme
    [Plate.f3d, Top-left-enc.stl, Top-right-enc.stl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]
2023-01-05 add stl for switch plate
    [top.FCStd, top.stl]
2023-01-05 update pcb
2023-01-05 fix components and pcbs
    [full.kicad_sch, right.kicad_sch, top.FCStd]
2023-01-10 fix bottom cutout plates
    [Bottom-cutout-choc-left.stl, Bottom-cutout-choc-right.stl, Bottom-cutout-left.stl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]
2023-01-19 improve 3d printed cases
    [Plate.f3d, Top-left-enc.stl, Top-right-enc.stl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]
2023-02-16 migrate to my component library
    [Rotary Encoder.step, full.kicad_sch]
2023-02-16 update 3d files
    [Bottom-cutout-choc-left.stl, Bottom-cutout-choc-right.stl, Bottom-cutout-left.stl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]
2023-02-16 fix ChocV2 footprint
2023-02-17 remove unsupported case files
    [BottomCutout.f3d, Plate.f3d, bottom-cutout-Edge_Cuts.dxf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]
2023-02-17 update bottom
    [bottom.kicad_pcb]
2023-02-17 add pcb 3d
    [bottom.dxf]
2023-02-18 add case files
    [Bottom-cutout-choc.stl, Bottom-cutout.stl, Top-left-enc.stl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]
2023-02-18 update pcb silkscreen
2023-02-20 add magnet holes, fix leg holes
    [bottom_case v10_left-legs.stl, bottom_case v10_left-thin.stl, bottom_case v10_left.stl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]
2023-02-20 restore bottom files
    [bottom-curved.dxf, bottom.dxf, bottom.kicad_pcb]
2023-02-25 top-mount usb-c
    [full.kicad_sch]
2023-02-25 update cases
    [top_case v15_left-wired-no-enc-thin.stl, top_case v15_left-wired-no-enc.stl, top_case v15_left-wired-thin.stl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]
2023-03-09 small update for bottom case
    [bottom_case v10_left-legs.stl, bottom_case v10_left-thin.stl, bottom_case v10_left.stl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]
2023-03-21 small case updates
    [bottom_case v17_left-legs.stl, bottom_case v17_left-thin.stl, bottom_case v17_left.stl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]
2023-03-21 restore cover files
    [cover-hole.dxf, cover.dxf]
2023-04-14 new wireless case
    [top_case v20_left-wireless-battery-thin.stl, top_case v20_left-wireless-battery.stl, top_case v20_right-wireless-battery-thin.stl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]
2023-05-18 improve new wireless case
    [top_case v20_left-wireless-battery-thin.stl, top_case v20_left-wireless-battery.stl, top_case v20_right-wireless-battery-thin.stl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]
2023-09-27 restore hole for power switch in wireless cases
    [top_case v23_left-wired-no-enc-thin.stl, top_case v23_left-wired-no-enc.stl, top_case v23_left-wired-thin.stl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]
2023-09-30 fix battery cover thickness, add leg cutouts
    [bottom_case v23_left-thin.stl, bottom_case v23_left.stl, bottom_case v23_right-thin.stl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]
2023-11-20 fix mcu hole in battery case
    [bottom_case v25_left-thin.stl, bottom_case v25_left.stl, bottom_case v25_right-thin.stl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]
